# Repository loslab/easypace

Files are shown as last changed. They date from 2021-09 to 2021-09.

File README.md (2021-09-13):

# Easypace
Open source biphasic pulse generator for electrical stimulation of tissues
developed by Oliver Schneider at the µOrganoLab & Fraunhofer Institute for Interfacial Engineering and Biotechnology (IGB)

https://github.com/loslab/easypace

Easypace was originally built for pacing cardiac tissues in microfluidic Organ-on-Chip systems, however it can be certainly used
for other purposes. It generates adjustable biphasic pulses with frequencies of ~ 0.1-10 Hz, 
amplitudes of up to ~ 12.5 V and pulsewidths of ~ 1 - 200 ms.
Generally it can also be just an idea/ starting point for your own improved pacer :rocket:.

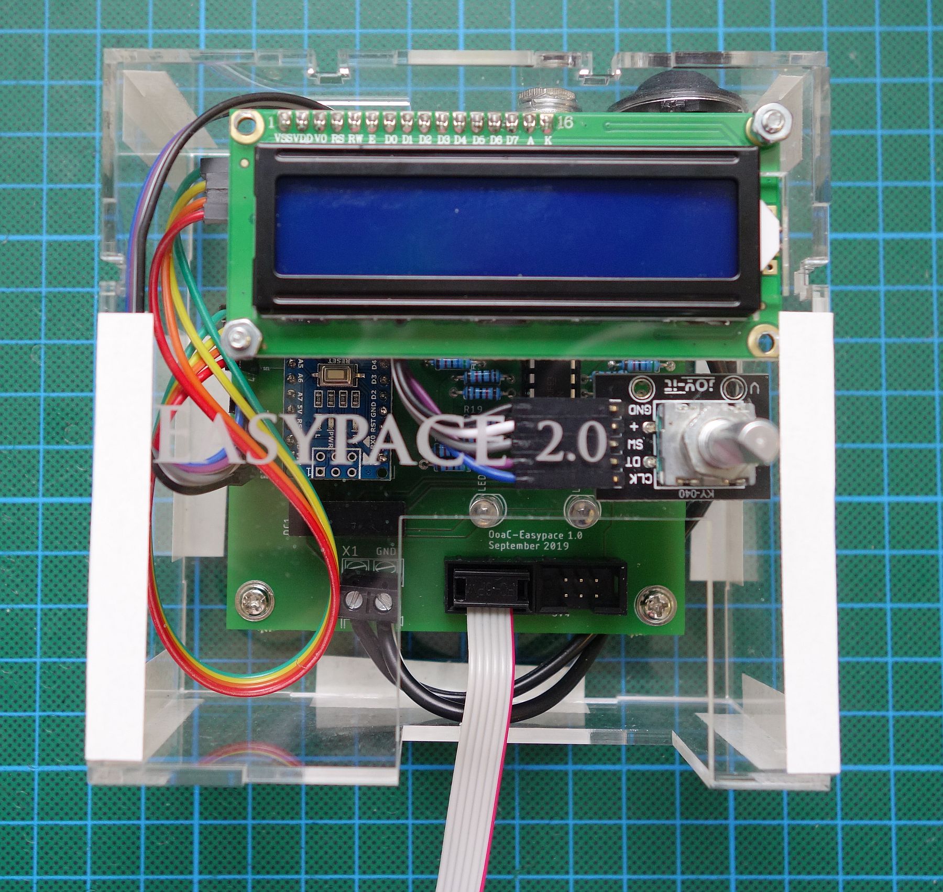
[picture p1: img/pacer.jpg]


---
### Features 

* 2 independently controllable pulseforms, 4 outputs in total
* Arduino-based, beginner-friendly assembly, hand-solderable
* manual control as well as scriptable remote control
* fairly cheap (cost of all parts < 100 €)

### Instructions
Check out the [wiki](https://github.com/loslab/easypace/wiki) for assembly & usage instructions

### Problems, questions, bugs, feedback and suggestions
I'm not a trained electrial engineer, so don't expect a professional build. I tinkered around with Easypace during my phd studies to build a cheap, 
scaleable system for pacing multiple tissues in cardiac Organ-on-Chip systems which I could adjust to my needs and control remotely.
We are happy about any feedback on Easypace. Just tell us if you have any improvement ideas and open a pull request or get in touch via ghilorevilo@posteo.de.

### License
Please cite Easypace if it helps you in your research.

This project is licensed under a BSD 3-Clause license. See the [LICENSE](LICENSE) file for details.

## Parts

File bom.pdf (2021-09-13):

Name | Info | Link | Art. No. | Price per item [€]

Needed
amounts Total price [€]

ICs
Spannungsreferenz, fest, 2,5 V, TO-92 | 2.5 V voltage reference | https://www.reichelt.de/spannunLM (https://www.reichelt.de/spannungsreferenz-fest-2-5-v-to-92-lm-285-z2-5-p39449.html) 285-Z2,5 | 0,37 | 1 | 0,37
DC/DC-Wandler AM2D-Z, 2 W, 15 V, 2x 66 mA, SIL-12 V -> 15 V voltage converter | | https://www.reichelt.de/dc-dc-wSIM2-1215D SIL7 | 6,62 | 1 | 6,62
Operationsverstärker, Quad, 1.2 MHz, DIL-14 | Opamp | https://www.reichelt.de/operatioLM (https://www.reichelt.de/operationsverstaerker-quad-1-2-mhz-dil-14-lm-324-n-p248019.html?trstct=pos_7&nbc=1) 324 N | 0,34 | 1 | 0,34
D/A-Wandler, 12-bit, 2-Kanal, SPI, 2,7 ... 5,5 V, DIP-DAC | | https://www.reichelt.de/d-a-wanMCP (https://www.reichelt.de/d-a-wandler-12-bit-2-kanal-spi-2-7--5-5-v-dip-14-mcp-4922-e-p-p90090.html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) 4922-E/P | 2,8 | 1 | 2,8
Arduino Nano | Arduino Nano | https://eckstein-shop.de/HIMALAAR10002 (https://eckstein-shop.de/HIMALAYAbasicNanoV32C0BoardATMEGA328PArduinokompatibelCH340Gmini-USBUARTIC5V16MHznichtgelC3B6tet) | 4,95 | 1 | 4,95

Hardware
LED, 5 mm, bedrahtet, rot, 4,5 mcd, 60° | LEDs to indicate pacing | https://www.reichelt.de/led-5-m (https://www.reichelt.de/led-5-mm-bedrahtet-rot-4-5-mcd-60--led-5mm-rt-p10233.html?trstct=pol_5&nbc=1) LED 5MM RT | 0,07 | 2 | 0,14
Anschlussklemme, 2-pol, Ø 2 mm, RM 5,08 | connector of Vin to board | https://www.reichelt.de/anschlu (https://www.reichelt.de/anschlussklemme-2-pol-2-mm-rm-5-08-akl-101-02-p36605.html?trstct=pol_10&nbc=1) AKL 101-02 | 0,23 | 1 | 0,23
40pol. Stiftleiste, gerade, RM 2,54 | pinheader for Display/ Rotary encoder, just break off the amount of pins you need | https://www.reichelt.de/40pol-stSL (https://www.reichelt.de/40pol-stiftleiste-gerade-rm-2-54-sl-1x40g-2-54-p19506.html?trstct=pol_0&nbc=1) 1X40G 2,54 | 0,21 | 1 | 0,21
Pinheader, 2x2 | pinheader to get output signals | https://www.reichelt.de/stiftleistMPE (https://www.reichelt.de/stiftleisten-2-54-mm-2x02-gerade-mpe-087-2-004-p119892.html?trstct=pol_14&nbc=1) 087-2-004 | 0,1 | 2 | 0,2
Wannenbuchse 2x3 | box connector to connector board, transferring all 4 signals | https://www.reichelt.de/wannenWSL (https://www.reichelt.de/wannenstecker-6-polig-gerade-wsl-6g-p85732.html?&trstct=pol_7&nbc=1) 6G | 0,25 | 1 | 0,25
Buchsenleisten 2,54 mm, 1X16, gerade | sockets for Arduino, cut off last pin
to fit Arduino pins
https://www.reichelt.de/buchsenMPE (https://www.reichelt.de/buchsenleisten-2-54-mm-1x16-gerade-mpe-094-1-016-p119919.html) 094-1-016 | 0,34 | 2 | 0,68
IC-Sockel, 14-polig, doppelter Federkontakt | IC socket | https://www.reichelt.de/ic-sockeGS (https://www.reichelt.de/ic-sockel-14-polig-doppelter-federkontakt-gs-14-p8206.html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) 14 | 0,05 | 2 | 0,1
Einbaubuchse Zentraleinbau, Ø außen: 5,6 mm, Ø | Barrel connector, alternative: cable (https://www.reichelt.de/in/de/adapterkabel-5-m-dc-buchse-freies-ende-rnd-205-01309-p286361.html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) | https://www.reichelt.de/einbaubHEBL (https://www.reichelt.de/einbaubuchse-zentraleinbau-aussen-5-6-mm-innen-2-5-mm-hebl-25-p8525.html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) 25 | 0,6 | 1 | 0,6
Wippenschalter rund, 1x Ein - Aus | on/ off rocker switch | https://www.reichelt.de/wippensWS (https://www.reichelt.de/wippenschalter-rund-1x-ein-aus-ws-r13-112-aaaa-p105442.html?trstct=pol_2&nbc=1) R13-112 AAAA | 0,9 | 1 | 0,9
Steckernetzteil, 18 W, 12 V, 1,5 A, stabilisiert | 12 V power supply | https://www.reichelt.de/steckernVT-3237 (https://www.reichelt.de/steckernetzteil-18-w-12-v-1-5-a-stabilisiert-vt-3237-p215626.html?trstct=pol_0&nbc=1) | 4,81 | 1 | 4,81
Character 16x2 LCD Display Module 1602 White on LCD | | https://eckstein-shop.de/CharactCP02013 | 5,08 | 1 | 5,08
Entwicklerboards - Kodierter Drehschalter | Rotary Encoder | https://www.reichelt.de/in/de/enDEBO (https://www.reichelt.de/in/de/entwicklerboards-kodierter-drehschalter-debo-rot-switch-p239260.html?r=1) ROT SWITCH | 2,65 | 1 | 2,65
Kontermutter für Potentiometerknöpfe, schwarz | nut to need to fix encoder | https://www.reichelt.de/in/de/koP4-MUTTER (https://www.reichelt.de/in/de/kontermutter-fuer-potentiometerknoepfe-schwarz-p4-mutter-p13757.html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) | 0,3 | 1 | 0,3
PC Schrauben M3 x 1/4 Zoll, 50 Stück | M3 screws, fix board if desired | https://www.reichelt.de/de/de/pST (https://www.reichelt.de/de/de/pc-schrauben-m3-x-1-4-zoll-50-stueck-st-screwm3-p190896.html?r=1) SCREWM3 | 5 | 1 | 5
Distanzhülsen, Metall, 6-Kant, M3, 12mm | mounting spacer, fix board if desired | https://www.reichelt.de/distanzhDI (https://www.reichelt.de/distanzhuelsen-metall-6-kant-m3-12mm-di-12mm-p44769.html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) 12MM | 0,13 | 4 | 0,52

Female to Female Jumper Wires - 40PIN + 15cm + jumper wire pins, connection of
display + rotary encoder
https://eckstein-shop.de/FemaletAF266 (https://eckstein-shop.de/FemaletoFemaleJumperWires-40PIN2B15cm2B10Farbe2B28AWG7strands4036AWG) | 4,7 | 1 | 4,7
Rs | various resistors
Widerstand, Metallschicht, 220 Ohm, 0207, 0,6 W, 1% | | https://www.reichelt.de/widerstaMETALL (https://www.reichelt.de/widerstand-metallschicht-220-ohm-0207-0-6-w-1--metall-220-p11627.html) 220 | 0,08 | 2 | 0,16
Widerstand, Metallschicht, 10,0 kOhm, 0207, 0,6 W, 1% | | https://www.reichelt.de/widerstaMETALL (https://www.reichelt.de/widerstand-metallschicht-10-0-kohm-0207-0-6-w-1--metall-10-0k-p11449.html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) 10,0K | 0,08 | 1 | 0,08

Widerstand, Metallschicht, 1,00 kOhm, 0207, 0,6 W, 1% | https://www.reichelt.de/widerstaMETALL (https://www.reichelt.de/widerstand-metallschicht-1-00-kohm-0207-0-6-w-1--metall-1-00k-p11403.html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) 1,00K | 0,08 | 1 | 0,08
Widerstand, Metallschicht, 11,0 kOhm, 0207, 0,6 W, 1% | https://www.reichelt.de/widerstaMETALL (https://www.reichelt.de/widerstand-metallschicht-11-0-kohm-0207-0-6-w-1--metall-11-0k-p11466.html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) 11,0K | 0,08 | 8 | 0,64
Widerstand, Metallschicht, 56,0 kOhm, 0207, 0,6 W, 1% | https://www.reichelt.de/widerstaMETALL (https://www.reichelt.de/widerstand-metallschicht-56-0-kohm-0207-0-6-w-1--metall-56-0k-p11879.html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) 56,0K | 0,08 | 8 | 0,64
| | | | Total | 43,05

Connector-board
Printstecker, Einzelstecker, gerade, 2-polig | connetor to crocodile clamps | https://www.reichelt.de/printste (https://www.reichelt.de/printstecker-einzelstecker-gerade-2-polig-pss-254-2g-p14907.html?trstct=pol_1&nbc=1) PSS 254/2G | 0,02 | 4 | 0,08
Widerstand, Metallschicht, 100 Ohm, 0207, 0,6 W, safety resistor | | https://www.reichelt.de/in/de/wMETALL (https://www.reichelt.de/in/de/widerstand-metallschicht-100-ohm-0207-0-6-w-1--metall-100-p11457.html?r=1) 100 | 0,08 | 4 | 0,32
Wannenbuchse 2x3 | box connector to pacer | https://www.reichelt.de/wannenWSL (https://www.reichelt.de/wannenstecker-6-polig-gerade-wsl-6g-p85732.html?&trstct=pol_7&nbc=1) 6G | 0,25 | 1 | 0,25
Flachbandkabel AWG28, 24-pol., grau, 3m-Ring | connector cable, 24 wires -> take 6 wires per cable | https://www.reichelt.de/flachbanAWG (https://www.reichelt.de/flachbandkabel-awg28-24-pol-grau-3m-ring-awg-28-24g-3m-p47642.html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) 28-24G 3M | 6,75 | 1 | 6,75
Pfostenbuchse, 6-polig, mit Zugentlastung | IDC socket for connector cable | https://www.reichelt.de/pfosten (https://www.reichelt.de/pfostenbuchse-6-polig-mit-zugentlastung-pfl-6-p53153.html?trstct=pol_12&nbc=1) PFL 6 | 0,26 | 2 | 0,52

Connector-Cables with Alligator Clips
Kupplungs-Leergehäuse, Crimptechnik, 2-polig | housing for 2-wire connectors | https://www.reichelt.de/kupplunPSK (https://www.reichelt.de/kupplungs-leergehaeuse-crimptechnik-2-polig-psk-254-2w-p14857.html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) 254/2W | 0,01 | 4 | 0,04
Crimpkontakte für psk 254/..., 20 Stück | Crimp contacts, better get more as you will mess up some | https://www.reichelt.de/crimpkoPSK-KONTAKTE (https://www.reichelt.de/crimpkontakte-fuer-psk-254--20-stueck-psk-kontakte-p14861.html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) | 0,24 | 1 | 0,24
Crimpzange, PSK-Kontakte | Crimping pliers, get only if you
don't have one yet and want to crimp your crocodile clamp connectors
https://www.reichelt.de/crimpza (https://www.reichelt.de/crimpzange-psk-kontakte-crimpzange-psk-p6844.html?nbc=1&trstct=lsbght_sldr::14857) CRIMPZANGE PSK | 19,46 | 1 | 19,46

Kupferlitze isoliert, 10 m, 4 x 0,25 mm², sw/gn/rt/bcables which can be crimped
(AWG24..30), alternative (https://www.reichelt.de/in/de/kupferlitze-isoliert-10-m-1-x-0-14-mm-rot-litze-rt-p10297.html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))
| https://www.reichelt.de/in/de/kuLITZE (https://www.reichelt.de/in/de/kupferlitze-isoliert-10-m-4-x-0-25-mm-sw-gn-rt-bl-litze-swgnrtbl-p245114.html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) SWGNRTBL | 7,3 | 1 | 7,3
Mueller Electric Kupfer Krokodilklemme, 6mm, 5A crocodile clamps | https://de.rs-online.com/web/p/ (https://de.rs-online.com/web/p/krokodilklemmen/7566709/) 756-6709 | 1,134 | 10 | 11,34

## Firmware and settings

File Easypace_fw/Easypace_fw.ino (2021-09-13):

/*

Firmware for Arduino-based pulsegenerator, applicable for, e.g., pacing of cardiac tissues
written by Oliver Schneider (ghilorevilo@posteo.de), September 2021

follow the instructions for assembling the hardware components and upload the firmware to your Arduino Nano

The pulsegenerator offers the output of 2 independently controllable biphasic pulse signals characterized by their:
- frequency (Hz)
- pulsewidth (ms)
- pulsevoltage (V)
- polarity (positive pulse or negative pulse first)
Each pulse signal is further output by the Opamp in 2 independent lines,
such that you can pace 4 samples simultaneously:
- DAC1 -> S1, S2; DAC2 -> S3, S4

sample output pulse:

Voltage

^        w
|      <-->
|      ####               #### ^ 
|      #  #               #  # | U
|      #  #               #  # |
|      #  #               #  # v
|#######--#--##############--#--##########----> time
|         #  #               #  #
|         #  #               #  #
|         #  #               #  #
|         ####               ####
|
|               f
|      <------------------>

the pulsegenerator can be controlled either 
- manually with the rotary encoder or
- remotely via Serial commands when connecting the Arduino via USB to a computer (baudrate set to 9600)
    supported serial commands:
    - GETPAR -> returns currently set pacing parameter
    - SETREM ON/OFF -> set pacer into remote (ON) or manual (OFF) mode
    - SETF f1 f2 -> sets frequency of channel 1 to f1, of channel 2 to f2
    - SETU U1 U2 -> sets voltage of channel 1 to U1, of channel 2 to U2
    - SETW w1 w2 -> sets pulsewidth of channel 1 to w1, of channel 2 to w2
    - SETPOL Pol1 Pol2 -> sets polarity of channel 1 to Pol1 (POS or NEG), of channel 2 to Pol2 (POS or NEG)
    - SETON ONstate1 ONstate2 -> sets pacing on channel 1 to Onstate1 (ON or OFF), of channel 2 to ONstate2 (ON or OFF)


notes: 
- due to individual variations in hardware components a slight drift of the zero-value might occur
  you can check for a drift by connecting a voltmeter to a signal-output (connect signal + ground),
  switch on the pacer and record the voltage in the idle state (pacing not turned on) U_idle.
  Then you can set the Variable DAC_correction to U_idle/0.0062
  (e.g. offset of +0.024 V -> DAC_correction = 0.024/0.0062 = 3.87 --> change line 74 to int DAC_correction = 4)
- timing is currently controlled by calling millis() which did not pose any issues for our applications (pulsewidths > 5 ms used)
  if timing is more crucial, calls to millis() might be replaced with micros()

    
*/

#include <MCP492X.h>            // DAC control
#include <LiquidCrystal_I2C.h>  // display control
#include <CommandParser.h>      // helper library for parsing of serial commands

#define PIN_SPI_CHIP_SELECT 10 // CS Pin 10
#define PIN_LED2 6
#define PIN_LED1 7
#define PIN_SHDN 8 // shutdown pin of DAC

#define PinA 2
#define PinB 3
#define PushButtonPin 4

int DAC_correction = 0;

//#######################################
// rotary encoder variables

#define rightTurn 2 // possible user interactions
#define leftTurn 3
#define pushButton 1
#define nothingPressed 0

volatile byte aFlag = 0; // control variables of encoder, based on https://www.instructables.com/Easy-Arduino-Menus-for-Rotary-Encoders/
volatile byte bFlag = 0;
volatile byte encoderPos = 0;
volatile byte oldEncPos = 0; // stores the last encoder position value 
volatile byte reading = 0;   // reading of interrupt pins  
boolean RotLeft_Flag = 0;    // flag to indicate leftwards rotation (-> false indicates right rotation)

bool newEncMovement = 0;
byte EncMovement = 0;

byte inputAction = nothingPressed;

bool PushBounceLock = LOW;  // for pushbutton debouncing
long PushLastPress = millis();
bool buttonPushed = LOW;

//#######################################
// variables for handling serial input (Parser)

const byte numChars = 32;
char receivedChars[numChars];
char tempChars[numChars];        // temporary array for use when parsing

boolean newData = false;

typedef CommandParser<7, 2, 6, 8, 32> MyCommandParser; 
// adjust parser to nr of expected commands to minimize memory consumption:
// parameters: 
// 7 stored commands,
// 2 allowed args for each command,
// 6 byte (= 6 chars) command name length,
// 8 byte max argument size, (e.g. 64-bit int would be 8 byte)
// 32 char max length of response message

MyCommandParser parser;

const char* POS = "POS";
const char* NEG = "NEG";
const char* ON = "ON";
const char* OFF = "OFF";

//#######################################
// menu options

// general control modes manual/ remote, stored in variable control_mode
#define manual 0
#define remote 1
byte control_mode = manual;

// menu options for manual control
#define mainMenu 0
#define adjustParameter 1

byte menustate = mainMenu;
byte menupage = 0;
byte cursor = 0;  // can be 0 or 1 (2 lines of display)
byte menuselection = 0; // = menupage + cursor

//#######################################
// variables for pacing control

// Signal 1 parameters
float S1_f = 1.0;       // frequency in Hz
float S1_w = 50.0;      // pulsewdth in ms
float S1_U = 5.0;       // voltage of biphasic pulse
float S1_T = (1/S1_f)*1000 - 2*S1_w;    // calculated period length in ms
bool S1_on = false;     // on/off pacing toggle
bool S1_pol = false;      // polarity of first pulse: false -> - first, true -> + first

// Signal 2 parameters
float S2_f = 1.0;       // frequency in Hz
float S2_w = 50.0;      // pulsewdth in ms
float S2_U = 5.0;       // voltage of biphasic pulse
float S2_T = (1/S2_f)*1000 - 2*S2_w;    // calculated period length in ms
bool S2_on = false;     // on/off pacing toggle
bool S2_pol = false;      // polarity of first pulse: false -> - first, true -> + first

// variables used for adjusting signal parameters
// specify range for allowed parameter values
float adj_f = S1_f; // (use just one buffer variable here in future?)
float min_f = 0.3;  // (use define here in future?)
float max_f = 5.0;
float step_f = 0.1;

float adj_w = S1_w;
float min_w = 1.0;
float max_w = 300;
float step_w = 1.0;

float adj_U = S1_U;
float min_U = 0.0;
float max_U = 12.5;
float step_U = 0.1;

bool adj_on = S1_on;
bool adj_pol = S1_pol;

// timing variables 
long currtime = millis();
long switchtime = currtime;     // switchtime used for blinking animation in ui during setting of param
long updatetime = switchtime;   // updatetime used to control how often parameterchanges are updated on the display
bool blinking = HIGH;

//##############################
// variables for pulse states

#define state_zero 0
#define state_p1 1
#define state_p2 2

byte S1_pulse_state = state_zero;
byte S2_pulse_state = state_zero;

long S1_statetime = 0;
long S2_statetime = 0;

// specifies DAC-value for pulse states (p1, p2, zero)
// is calculated later from set voltage and polarity order
int S1_DAC_p1 = 0;
int S2_DAC_p1 = 0;

int S1_DAC_p2 = 0;
int S2_DAC_p2 = 0;

int S1_DAC_zero = 0;
int S2_DAC_zero = 0;


//##############################
// variables for adjustment menu

char parameter_to_adjust;
const int refreshtime = 50;     // msec for refreshing currently adjusted parameter
const int blinktime_on = 800;   // msec for blinking mode in menuselection
const int blinktime_off = 400;  // msec for blinking mode in menuselection
int blinktime = blinktime_on;

//################################
// display

LiquidCrystal_I2C lcd(0x27, 16, 2); // set up display type: 16x2
MCP492X myDac(PIN_SPI_CHIP_SELECT); // init DAC

//################################
// DAC control functions

// calculate needed DAC output to get desired voltage V
// 12-bit DAC -> 2^12 = 4096 values -> can take values from 0-4095
// Opamp converts signal: (U_DAC-2.5V)*(56kO/11kO)
// output 0 - 4095 gets converted to -12.727 V - 12.727 V
// theoret. output: 4095 to get 12.727 V
int calc_DAC(float V) {
    int DACOut = int(((V + 12.727)/25.454) * 4095.0)-DAC_correction;
    return DACOut;
}

// sets values S1_DAC_p1, S1_DAC_p2, S1_DAC_zero (= DAC output for specific state)
// corresponding to desired signal voltage

// so far does calculation for both channels
// todo: can be definitely improved to do on specified channel also
// as done only once not considered too time critical right now
// arrays, e.g. U[channel] would definitely help
void set_DACvals(){
    
    // pulsestates for channel 1
    if (S1_pol == true) {   // -> first state S1_DAC_p1 positive voltage, second S1_DAC_p2 negative voltage
    S1_DAC_p1 = calc_DAC(-S1_U);
    S1_DAC_p2 = calc_DAC(S1_U); }
    
    else { // -> first pulse negative
    S1_DAC_p1 = calc_DAC(S1_U);
    S1_DAC_p2 = calc_DAC(-S1_U); }
    
    // pulsestates for channel 2, similar to above
    if (S2_pol == true) {
    S2_DAC_p1 = calc_DAC(-S2_U);
    S2_DAC_p2 = calc_DAC(S2_U); }
    
    else {
    S2_DAC_p1 = calc_DAC(S2_U);
    S2_DAC_p2 = calc_DAC(-S2_U); }    
    
    // set zerostates for both channels (should be same)
    S1_DAC_zero = calc_DAC(0.0);
    S2_DAC_zero = S1_DAC_zero;
}

// sets DAC output of channel chan to specified state
// uses precalculated DAC-values S1_DAC_p1, S1_DAC_p2, S1_DAC_zero

// chan is 1 or 2, state is state_zero, state_p1, state_p2
// for correct writing to DAC via library:
// set gain + enable bits explicitely, otherwise gain would be 1
void write_DAC(int chan, byte state) {
    switch(state) {
        case state_zero:
            if (chan == 1) {myDac.analogWrite(0, 0, 0, 1, S1_DAC_zero);}
            else if (chan == 2) {myDac.analogWrite(1, 0, 0, 1, S2_DAC_zero);}
            // todo: ugly solution, can be simplified to array DAC_zero[channel]
        break;

        case state_p1:
            if (chan == 1) {myDac.analogWrite(0, 0, 0, 1, S1_DAC_p1);}
            else if (chan == 2) {myDac.analogWrite(1, 0, 0, 1, S2_DAC_p1);}
         
        break;
        
        case state_p2:
            if (chan == 1) {myDac.analogWrite(0, 0, 0, 1, S1_DAC_p2);}
            else if (chan == 2) {myDac.analogWrite(1, 0, 0, 1, S2_DAC_p2);}
        break;
    }
}

//################################
// Arduino setup function

void setup() {
    myDac.begin();  // take care, as VOut = 0 V -> output to pacer will be -12.7 V, leading to an initial pulse during startup
    setupPins();
    updatePacer();  // get DAC as quickly as possible to put out 2.5 V -> 0V after OPAMP    
    lcd.begin();
    
    startscreen();
    print_MainMenu(menupage,cursor);
    
    Serial.begin(9600); // todo: think about where to place, start here already or enable manually? 
    
    // link input commands to callback functions
    // "dd" means 2 doubles as input, e.g. "SETF 1.0 1.5"
    parser.registerCommand("SETREM", "s", &setrem);  //
    parser.registerCommand("GETPAR", "", &getpar);  //
    parser.registerCommand("SETF", "dd", &setf);    //
    parser.registerCommand("SETU", "dd", &setu);    //
    parser.registerCommand("SETW", "dd", &setw);    //
    parser.registerCommand("SETPOL", "ss", &setpol);//
    parser.registerCommand("SETON", "ss", &seton);  //
}

//################################
// Arduino loop

void loop() {
    readInput();    // continuously check for input
    handleInput();
    runPacer();     // constantly perform required DAC state changes for correct pacing
}

// setting up pins on first startup
void setupPins()  {
  pinMode(PIN_LED1, OUTPUT);
  pinMode(PIN_LED2, OUTPUT);
  pinMode(PIN_SHDN, OUTPUT);
  digitalWrite(PIN_LED1, HIGH);
  digitalWrite(PIN_LED2, HIGH);
  digitalWrite(PIN_SHDN, HIGH); // enable DAC
  
  pinMode(PinA, INPUT_PULLUP); // set pinA as an input, pulled HIGH to the logic voltage  
  pinMode(PinB, INPUT_PULLUP); // set pinB as an input, pulled HIGH to the logic voltage  
  attachInterrupt(0,PinA_INT,RISING); // set interrupt on PinA, looking for a rising edge 
  attachInterrupt(1,PinB_INT,RISING);
  pinMode(PushButtonPin,INPUT_PULLUP);
  }

// interrupt for PinA
void PinA_INT(){
  cli(); //stop interrupts happening before we read pin values
  reading = PIND & 0xC; // read all eight pin values then strip away all but pinA and pinB's values
  if(reading == B00001100 && aFlag) { //check that we have both pins at detent (HIGH) and 
                                      //that we are expecting detent on this pin's rising edge
  EncMovement = rightTurn;
  newEncMovement = 1;
    bFlag = 0; //reset flags for the next turn
    aFlag = 0; //reset flags for the next turn
  }
  else if (reading == B00000100) bFlag = 1; //signal that we're expecting pinB to signal 
                                            //the transition to detent from free rotation
  sei(); //restart interrupts
}

// interrupt for PinB
void PinB_INT(){
  cli(); //stop interrupts happening before we read pin values
  reading = PIND & 0xC; //read all eight pin values then strip away all but pinA and pinB's values
  if (reading == B00001100 && bFlag) { //check that we have both pins at detent (HIGH) and 
                                       //that we are expecting detent on this pin's rising edge
  EncMovement = leftTurn;
  newEncMovement = 1;
    bFlag = 0; //reset flags for the next turn
    aFlag = 0; //reset flags for the next turn
  }
  else if (reading == B00001000) aFlag = 1; //signal that we're expecting pinA to signal 
                                            //the transition to detent from free rotation
  sei(); //restart interrupts
}
  
// startup screen
void startscreen()  {
  lcd.setCursor(0,0);
  lcd.print("  EasyPace 2.0  ");
  lcd.setCursor(0,1);
  lcd.print(" ready to pace  ");

  for (int i=17; i>2; i--)
  {
    
    int delaytime = i*i*2;
    delay(delaytime);
    digitalWrite(PIN_LED1, HIGH);
    delay(70);
    digitalWrite(PIN_LED2, HIGH);
    delay(30);
    digitalWrite(PIN_LED1, LOW);
    delay(30);
    digitalWrite(PIN_LED2, LOW);
  }
  
  lcd.clear();
}

// print menu structure upon navigation
void print_MainMenu(byte menupage, byte Cursor){
  lcd.clear();
  //or do it as array char mainMenu_Entries[][17] = {"running:", "set par", "quick U:", "set U"};
  switch(menupage) {
    case 0:
    lcd.setCursor(0,0);
    lcd.print(" running:");
  if(S1_on == true) {lcd.print("ON");} else {lcd.print("OFF");}
    lcd.setCursor(0,1);
    lcd.print(" set f:"); lcd.print(S1_f);
    break;
    case 1:
    lcd.setCursor(0,0);
    lcd.print(" set f:"); lcd.print(S1_f);
    lcd.setCursor(0,1);
    lcd.print(" set W:"); lcd.print(S1_w);
    break;
    case 2:
    lcd.setCursor(0,0);
    lcd.print(" set W:"); lcd.print(S1_w);
    lcd.setCursor(0,1);
    lcd.print(" set U:"); lcd.print(S1_U);
    break;

    case 3:
    lcd.setCursor(0,0);
    lcd.print(" set U:"); lcd.print(S1_U);
    lcd.setCursor(0,1);
    lcd.print(" set polar:");
    if(S1_pol == true) {lcd.print("+");} else {lcd.print("-");}
    break;

  }
  
  lcd.setCursor(0,Cursor);
  lcd.print(">");
}

// actions to perform on encoder input left/right/push
// perhaps easier: array of function pointer? No switch needed anymore -> action[0/1/2]
void mainMenu_actions()  {
  
  switch (inputAction)  {
    case leftTurn:    // decrease counter of program step    
        if (menupage > 0 && cursor == 0) {menupage--; print_MainMenu(menupage,cursor);}
    else if (cursor == 1) {cursor--; print_MainMenu(menupage,cursor);}// decrement cursor by 1 
    break;
    
    case rightTurn: // increase counter of program step
    if (menupage < 3 && cursor == 1)  {menupage++; print_MainMenu(menupage,cursor);}
    else if (cursor == 0)  {cursor++; print_MainMenu(menupage,cursor);}      
    break;
    
    case pushButton:
    menuselection = menupage + cursor;
    switchtime = millis(); updatetime = millis();
    lcd.clear();
      
        switch (menuselection)  {
        case 0: // running
          parameter_to_adjust = 'o';
          adj_on = S1_on;
          menustate = adjustParameter;
        break; 
        
        case 1: // set f
          parameter_to_adjust = 'f';
          adj_f = S1_f;
          menustate = adjustParameter;    
        break;
        
        case 2: // set W
          parameter_to_adjust = 'w';
          adj_w = S1_w;
          menustate = adjustParameter;
        break;
          
        case 3: // set U
          parameter_to_adjust = 'U';
          adj_U = S1_U;
          menustate = adjustParameter;      
        break;
        
        case 4: // set pulse polarity
          parameter_to_adjust = 'p';
          adj_pol = S1_pol;
          menustate = adjustParameter;      
        break;        
          } 
      break;
    
    case nothingPressed:
      break;
  }  
}

void adjustParameter_actions(char parameter)  {
// update visible variable
// possible parameters: 'o' (on/off), 'f', 'w', 'U'
// longer char as input?
   
  print_adjustParameter(parameter);
  
  switch (inputAction)  {
    case leftTurn:
    if (parameter == 'o') {
        if (adj_on == true)  {adj_on = false;}
      }
  
    else if (parameter == 'f')  {
        if (adj_f > min_f)  {adj_f = adj_f-step_f;}
    }
    
    else if (parameter == 'w')  {
    if (adj_w > min_w)  {adj_w = adj_w-step_w;}
    }
    
    else if (parameter == 'U')  {
    if (adj_U > min_U)  {adj_U = adj_U-step_U;}
    }    
    
    else if (parameter == 'p')  {
    if (adj_pol == true)  {adj_pol = false;}
    }
    
    break;
    
  case rightTurn:
    if (parameter == 'o') {
        if (adj_on == false)  {adj_on = true;}
      }
  
    else if (parameter == 'f')  {
        if (adj_f < max_f)  {adj_f = adj_f+step_f;}
    }
    
    else if (parameter == 'w')  {
        if (adj_w < max_w)  {adj_w = adj_w+step_w;}
    }
    
    else if (parameter == 'U')  {
        if (adj_U < max_U)  {adj_U = adj_U+step_U;}
    }
    
    else if (parameter == 'p') {
        if (adj_pol == false)  {adj_pol = true;}
      }
      
    break; 
    
    case pushButton:
    updatePacer();
    menustate = mainMenu;
    print_MainMenu(menupage, cursor);
    break;
  
    case nothingPressed:
      break;  
  }

}

// function called to update ui during parameter change
void print_adjustParameter(char parameter)  {

  currtime = millis();
  if (parameter == 'o') {
    if(currtime-switchtime > blinktime) {
    switchtime = currtime;
    if (blinking == LOW) {blinking = HIGH; blinktime = blinktime_on; lcd.setCursor(0,cursor); lcd.print("> running:"); lcd.print(adj_on);}
    else {blinking = LOW; blinktime = blinktime_off; lcd.clear(); lcd.setCursor(0,cursor); lcd.print("> running:"); }
    }
    
    if (blinking == HIGH)
    {
      if(currtime-updatetime > refreshtime) {updatetime = currtime; lcd.setCursor(0,cursor); lcd.print("> running:"); lcd.print(adj_on);}
    }   
  }

  else if (parameter == 'p') {
    if(currtime-switchtime > blinktime) {
    switchtime = currtime;
    if (blinking == LOW) {blinking = HIGH; blinktime = blinktime_on; lcd.setCursor(0,cursor); lcd.print("> set polar:"); 
        if (adj_pol == true)  {lcd.print("+");} else {lcd.print("-");}}
    else {blinking = LOW; blinktime = blinktime_off; lcd.clear(); lcd.setCursor(0,cursor); lcd.print("> set polar:"); }
    }
    
    if (blinking == HIGH)
    {
      if(currtime-updatetime > refreshtime) {updatetime = currtime; lcd.setCursor(0,cursor); lcd.print("> set polar:");
        if (adj_pol == true)  {lcd.print("+");} else {lcd.print("-");}}
    }   
  }
 
  else if (parameter == 'f'){
    if(currtime-switchtime > blinktime) {
    switchtime = currtime;
    if (blinking == LOW) {blinking = HIGH; blinktime = blinktime_on; lcd.setCursor(0,cursor); lcd.print("> set f:"); lcd.print(adj_f);}
    else {blinking = LOW; blinktime = blinktime_off; lcd.clear(); lcd.setCursor(0,cursor); lcd.print("> set f:"); }
    }

    if (blinking == HIGH)
    {
      if(currtime-updatetime > refreshtime) {updatetime = currtime; lcd.setCursor(0,cursor); lcd.print("> set f:"); lcd.print(adj_f);}
    }
  }
  
  else if (parameter == 'w'){
    if(currtime-switchtime > blinktime) {
    switchtime = currtime;
    if (blinking == LOW) {blinking = HIGH; blinktime = blinktime_on; lcd.setCursor(0,cursor); lcd.print("> set w:"); lcd.print(adj_w);}
    else {blinking = LOW; blinktime = blinktime_off; lcd.clear(); lcd.setCursor(0,cursor); lcd.print("> set w:"); }
    }

    if (blinking == HIGH)
    {
      if(currtime-updatetime > refreshtime) {updatetime = currtime; lcd.setCursor(0,cursor); lcd.print("> set w:"); lcd.print(adj_w);}
    }
  }
  
  else if (parameter == 'U'){
    if(currtime-switchtime > blinktime) {
    switchtime = currtime;
    if (blinking == LOW) {blinking = HIGH; blinktime = blinktime_on; lcd.setCursor(0,cursor); lcd.print("> set U:"); lcd.print(adj_U);}
    else {blinking = LOW; blinktime = blinktime_off; lcd.clear(); lcd.setCursor(0,cursor); lcd.print("> set U:"); }
    }

    if (blinking == HIGH)
    {
      if(currtime-updatetime > refreshtime) {updatetime = currtime; lcd.setCursor(0,cursor); lcd.print("> set U:"); lcd.print(adj_U);}
    }
  }

}
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

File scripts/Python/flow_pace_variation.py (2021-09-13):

# -*- coding: utf-8 -*-

"""

sample macro where a pump and the pacer are controlled in a coordinated way
all commands are logged with timestamps to explog.log to possibly sync events
ports are manually inserted, so make sure to know where the pacer is connected and adjust it accordingly
to check all ports call `print(serial.tools.list_ports)

various stages are displayed:
- vary pacing parameters, switch paced channel
- start/ stop pump
- vary pumprates
- start/ stop pump with combined pacing variation
"""

import serial
from time import sleep
import logging

#### setup logger and constants

logging.basicConfig(filename='explog.log', level=logging.DEBUG, format='%(asctime)s %(message)s')# encoding='utf-8', 

pump = serial.Serial()
pump.timeout = 0.2
pump.baudrate = 9600 # make sure to set same baudrate to pump
pump.port = 'COM8'
pump.open()

pacer = serial.Serial()
pacer.timeout = 0.2
pacer.baudrate = 9600
pacer.port = 'COM7'
pacer.open()

TSLEEP = 5
WAITCMD = 0.2

### define helper functions

def waitmin(min):
    logging.warning("waiting for " + str(min) + " min")
    print("### waiting for " + str(min) + " min ###")
    sleep (min*60)
    
def init_pump():
    """ inits pump to infusing + running """
    print("initing pump, set to infuse and start")
    logging.warning("initing pump, set to infuse and start")    
    
    writepump("STP")    
    writepump("DIR INF") # make sure pump is infusing
    # pump is already set to 50 µl/h
    # if new value is set pump has to be on stop before setting value with
    # RAT 50 UH (50 µl/h)
    writepump("RUN")

def init_pacer():
    """ after serial connection pacer does reboot ... wait until available """
    print("initing pacer, waiting 10 s for connection")
    logging.warning("initing pacer, waiting 10 s for connection")
    sleep(10)

def writepump(cmd):
    """
        writes cmd to pump, attaches \r and encodes message as byte
        reads response until pump.timeout occurs and logs + prints resonse
        response indicated by >
    """

    print(cmd)
    logging.warning(cmd)
    cmd = str.encode(cmd + '\r')
    pump.write(cmd)
    
    rawresp = pump.readline() # take care that timeout is specified above, will block otherwise
    resp = rawresp.decode("ascii").strip('\x02').strip('\x03')
    resp = "> " + resp
    print(resp)
    logging.warning(resp)
    
    sleep(WAITCMD)  # waits a short period after sending signal

def writepacer(cmd):
    """
        writes cmd to pacer, attaches \n and encodes messages as byte
        reads response
        response indicated by >
        
        communicating with the pacer just needs a call to `writepacer("SETON ON ON")`
    """

    print(cmd)
    logging.warning(cmd)
    cmd = str.encode(cmd + '\n')
    pacer.write(cmd)
        
    rawresp = pacer.read(1000) # reads up to 1000 bytes or until pacer.timeout occurs
    # expected answers short for setting values
    # longest answer if GETPAR sent
    
    resplines = rawresp.decode("ascii").splitlines()
    
    for line in resplines:
        print(line)
        logging.warning(line)
    
    sleep(WAITCMD)  # waits a short period after sending signal 

### main macro function

def controlmacro():
    logging.warning("### starting macro ###")
    print("### starting macro ###")
    
    # stage 1:     
    # subsequent pacing variation
    # pace chan1 for PACER_MIN, then rest REST_MIN, 
    # then pace chan2 for PACER_MIN, then rest REST_MIN
    # perform everything 3x
    
    # init pacer to 1 Hz, 50 ms, 10 V, negpol on both chan
    
    writepacer("SETREM ON")
    writepacer("SETF 1.0 1.0")
    writepacer("SETW 50.0 50.0")
    writepacer("SETU 10.0 10.0")
    writepacer("SETPOL NEG NEG")
    writepacer("GETPAR")
    
    PACER_MIN = 10
    REST_MIN = 10
    
    for i in range(3):
        writepacer("SETON ON OFF") # pace channel 1 for PACER_MIN
        waitmin(PACER_MIN)
        writepacer("SETON OFF OFF") # rest for REST_MIN
        waitmin(REST_MIN)
        writepacer("SETON OFF ON") # pace channel 2 for PACER_MIN
        waitmin(PACER_MIN)        
        writepacer("SETON OFF OFF") # rest for REST_MIN
        waitmin(REST_MIN)
    
    writepacer("GETPAR")
    waitmin(20) # wait for 20 more minute to stabilize signal
    # ~ 140 min elapsed
    
    # stage 2:
    # pumping rate variation
    # stop pump NOFLOW_MIN, start pump for ONFLOW_MIN
    # stop and restart 3x
     
    NOFLOW_MIN = 30
    ONFLOW_MIN = 30
    
    # 3 cycles of off-on
    for i in range(3):
        writepump("STP")
        waitmin(NOFLOW_MIN)
        writepump("RUN")
        waitmin(ONFLOW_MIN)    
    
    # ~ 320 min elapsed
    
    # stage 3:
    # pumping rate variation
    # flowrates [µl/h]: 200-400-600-400-200-50
    # keep pump for FLOWSTEP_MIN at specified pumping rate    
    
    FLOWSTEP_MIN = 10    
    
    writepump("STP")
    writepump("RAT 200 UH")
    writepump("RUN")
    waitmin(FLOWSTEP_MIN)
    
    writepump("STP")
    writepump("RAT 400 UH")
    writepump("RUN")
    waitmin(FLOWSTEP_MIN)
    
    writepump("STP")
    writepump("RAT 600 UH")
    writepump("RUN")
    waitmin(FLOWSTEP_MIN)    

    writepump("STP")
    writepump("RAT 400 UH")
    writepump("RUN")
    waitmin(FLOWSTEP_MIN)

    writepump("STP")
    writepump("RAT 200 UH")
    writepump("RUN")
    waitmin(FLOWSTEP_MIN)

    writepump("STP")
    writepump("RAT 50 UH")
    writepump("RUN")
    # set back to 50 µl/h when finished
 
    # ~ 320 min elapsed

    
    # stage 4:
    # combine pacing with pumping rate variation
    # stop pump + pace 30 min, enable pump again wo. pacing for 30 min
    
    # set basic pacer config
    writepacer("SETREM ON")
    writepacer("SETF 1.0 1.0")
    writepacer("SETW 50.0 50.0")
    writepacer("SETU 10.0 10.0")
    writepacer("SETPOL NEG NEG")
    writepacer("GETPAR")

    #3 cycles: stop pupmp + pace both channels for NOFLOW_MIN, then stop pacing, start pump for ONFLOW_MIN
    for i in range(3):
        writepacer("SETON ON ON")
        writepump("STP")
        waitmin(NOFLOW_MIN)
        writepacer("SETON OFF OFF")
        writepump("RUN")
        waitmin(ONFLOW_MIN)
    
    # ~ 500 min elapsed
    
    # repeat with different frequency
    # set f for both chan to 1.3 Hz
    writepacer("SETF 1.3 1.3")
    #3 cycles: pace both channels + stop pump -> stop pacing, start pump
    for i in range(3):
        writepacer("SETON ON ON")
        writepump("STP")
        waitmin(NOFLOW_MIN)
        writepacer("SETON OFF OFF")
        writepump("RUN")
        waitmin(ONFLOW_MIN)
    # ~ 680 min elapsed
    
    writepacer("GETPAR")    


    logging.warning("### macro finished ###")
    print("### macro finished ###")
    
if __name__ == "__main__":
    init_pump()
    init_pacer()
    controlmacro()
    
    pump.close()
    pacer.close()

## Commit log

2021-09-13 add firmware, samplemacros, cad(enclosure layout)
2021-09-13 add gitignore with entries for kicad-files so far
2021-09-13 add bom add pcbs: Easypace_v3 & Connectorboard
    [Connectorboard.kicad_pcb, Connectorboard.sch, Easypace_v3.kicad_pcb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]
